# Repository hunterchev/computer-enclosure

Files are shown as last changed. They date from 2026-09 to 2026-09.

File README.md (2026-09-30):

# Small-computer display enclosure, v2

Redesign of the three files that came in (`reference/front.stl`, `back.stl`,
`foot.stl`). Same 108 x 94 mm footprint and the same 86 x 65 mm display window,
but the stand now plugs into the back plate, every fastener is a printed
thumbscrew that actually has threads to bite into, and the whole thing is one
parametric OpenSCAD file so it can be re-cut for the real board.

| file | print it? | what it is |
|---|---|---|
| `enclosure.scad` | – | the generator (needs the `BOSL2/` submodule) |
| `front.stl` | yes | bezel + walls + 4 threaded corner bosses, 108 x 94 x 38 |
| `back.stl` | yes | 6 mm back plate: standoffs, tray, vents, dovetail groove |
| `stand.stl` | yes | tilt stand (15 degree lean-back), prints on its side |
| `stand_upright.stl` | optional | same stand at 0 degrees (`tilt=0`), case stands straight up |
| `screws.stl` | yes | 5 thumbscrews: 4 x 18 mm (back plate), 1 x 24 mm (stand lock) |
| `fit_check.stl` | first | just the top 1 mm of the back plate with the standoffs. 15 min print to confirm the board sits where the model thinks it does |
| `renders/` | – | previews of everything |
| `reference/` | – | the original three STLs, untouched |

## Getting the files

BOSL2 is a git submodule pinned to the commit this was built with, so clone
with it:

    git clone --recurse-submodules https://github.com/hunterchev/computer-enclosure.git

If you already cloned without it: `git submodule update --init`. The STLs
are committed, so you only need BOSL2 to change the design and re-export.

## What was wrong with the original

- **The foot screwed to the wrong part.** Its four holes lined up with four
  4.4 mm holes in the *side wall* of the front shell, so the screws had to go
  in from inside the case, behind the computer. The foot's own holes were
  4 mm, 3 to 4 mm deep, and unthreaded: an M4 in that is a friction fit,
  not a fastening.
- **The corner screws were marginal.** 2.5 mm pilots in the shell posts with
  3.4 mm clearance holes in the plate is a correct M3 self-tap layout, but
  the posts were about 6 mm across in a 2.4 mm wall, so there was ~1.7 mm of
  plastic around each thread. Usable, not durable, and it needed bought M3s.
- **Nothing located the back plate** on the shell except those four screws.
- **No ventilation and no port openings** apart from one 10 x 4 mm notch in
  the bottom wall, which the foot then covered.
- The front's mystery: an 86 x 65 window and eight pegs on the back plate
  (posts at the tray edge with arms reaching inward, four of them carrying
  2.8 mm pins on a 25 x 55 mm pattern) around a 74.6 x 56.6 mm tray. The
  pegs, tray, and the small U-clip are reproduced at the original coordinates. None of this identifies a specific computer, and the
  PDF that came with the files was a FedEx label, not a datasheet.

## What changed

**Stand.** The back plate has a 14 mm dovetail groove down its lower half,
open at the bottom edge. The stand carries the matching tongue: lower the case
onto it and it seats on the stand's shelf, leaning back 15 degrees. It cannot
tip forward or back because the tongue is captive in the groove. A fifth
thumbscrew goes through the stand into a threaded boss on the inside of the
plate as a lock, 20 mm right of centre so it misses the groove and the clip;
the head sits in the open bay between the two gussets, so it is reachable
with the case assembled. Set `stand_lock = false` to drop it.

**Fasteners.** Printed thumbscrews: 7 mm major, 2.5 mm pitch, 45 degree
flanks (prints upright, no support), 12 mm knurled head with a coin slot. The
corner bosses are 12 mm round, fused into the wall corners, threaded 14 mm
deep, so each screw engages about 12 mm of thread. The female threads are cut
with 0.25 mm radial clearance (`thread_clear`); the mating was checked by
boolean intersection in the model. If your printer runs tight, raise it to
0.3. If you would rather use metal: `fastener = "m3"` switches the bosses to
2.5 mm pilots and the plate to 3.4 mm holes with a countersink.

**Fit.** The plate has a 1.5 mm lip that enters the shell (0.2 mm per side),
so it locates itself before the screws go in.

**Cooling.** Ten slits in the top wall and ten slots in the back plate under
the board. With the case leaning back, air enters the plate slots and leaves
through the top.

**Ports.** `cutouts` is a list of `[side, along, z, w, h]`; the default is
one 12 x 8 mm notch at the back edge of the right wall, next to the tray's cable gap.

## Fitting the real computer

The interior is what the original implied, not what any datasheet says.
Measure the board and change these in `enclosure.scad`:

| variable | default | measure |
|---|---|---|
| `standoffs` | the original 8 pegs | `[x, post_y, arm_end_y, pin]`: post at the tray edge, arm reaching inward, pin on the arm end. Pins on the right pair at (34.5, ±27.5) and (9.5, ±27.5), plain rests on the left |
| `mount_style` | `"pin"` | `"screw"` gives 2.2 mm holes for M2.5 self-tappers instead of pins |
| `standoff_h` | 12 | clearance needed under the board (tallest part on its underside + 1) |
| `tray` / `tray_on` | 74.6 x 56.6 x 6 | the rim under the board, cable gap on the right; turn off if nothing lives there |
| `edge_clip` | on | the small 12 mm U-clip by the bottom wall that the original had |
| `window` | 86 x 65 | visible area of the display, plus 0.5 mm each way |
| `cutouts` | one notch | one entry per port: which wall, where along it, how far from the bezel face |
| `depth` | 38 | bezel face to plate: display + board + standoffs + 6 mm plate must fit in `depth - bezel` |

Clear interior is 103.2 x 89.2 mm by 35 mm deep (bezel inner face to plate
inner face), minus the four 12 mm corner bosses. Print `fit_check.stl` first
and drop the board on it before printing `back.stl`.

## Printing

| part | orientation | notes |
|---|---|---|
| front | bezel face down | as exported. No supports; the window chamfer is on the bed side. 0.2 mm layers, 4 walls |
| back | outer face down | as exported. The groove's undercuts print as a widening void, no supports. 4 walls, 40 % infill |
| stand | on its side | as exported (a flat side face is on the bed). 30 % infill is plenty |
| screws | heads down | as exported. 0.16 mm layers if you have them, 100 % infill or 6 walls. PETG threads better than PLA |
| fit_check | as exported | anything |

Assembly: drop the board on the pins, put the plate on (lip locates it), four
screws from the back, finger-tight. Slide the case down onto the stand's tongue,
then the lock screw from behind, between the gussets.

## Regenerating

    openscad --backend=manifold -o front.stl  -D 'part="front"'  enclosure.scad
    openscad --backend=manifold -o back.stl   -D 'part="back"'   enclosure.scad
    openscad --backend=manifold -o stand.stl  -D 'part="stand"'  enclosure.scad
    openscad --backend=manifold -o screws.stl -D 'part="screws"' enclosure.scad

`part="assembly"` previews it standing on the stand. The `chk_*` parts are
interference checks and should each come out empty (OpenSCAD prints "Current
top level object is empty"); the screw checks use `chk_phase` because a screw
at the wrong rotation always looks like it collides with its nut.

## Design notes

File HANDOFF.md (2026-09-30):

# Handoff: small-computer display enclosure redesign

Written 2026-09-28 for whoever picks this up next (human or another chat).
Project folder: `~/3-D Print/computer enclosure/`. Everything below is true of
the files as they sit there now. The README.md in the same folder is the
user-facing print guide; this file is the engineering trail.

## 1. What the user asked for

Hunter (hunter.chevaillier@reardenresearch.com) dropped three STLs from
`~/Downloads` (`front.stl`, `back.stl`, `foot.stl`) plus a PDF, and asked:

1. redesign it so the stand "actually goes into the back plate",
2. redesign the whole thing to be better, because the screws looked wrong,
3. print some screws,
4. fit it to "this exact computer", model unknown.

Follow-ups in the same conversation:
- "make me one with a regular angle too" -> an upright (0 degree) stand was
  exported as `stand_upright.stl`, then the user said "actually dont". The
  file was left in place and marked optional. A reclined wedge variant was
  started and deliberately abandoned; nothing of it remains.
- "are all the pegs the same on the backplate" -> no, and the user then said
  "make them align like the back plate i gave you at the start". The pegs
  were rebuilt to the original's exact geometry (section 5).

The PDF was a FedEx shipping label with personal names and addresses on it,
not a datasheet. It contains nothing about the computer. Don't reproduce its
contents anywhere.

## 2. What the original files were (measured, not guessed)

Measured with trimesh cross-sections; originals are kept untouched in
`reference/`.

| part | size (mm) | what it is |
|---|---|---|
| front | 108 x 94 x 38 | open shell: 3 mm bezel with an 86 x 65 window, 2.4 mm walls, r=4 corners, four corner posts with 2.5 mm blind holes 8.3 deep at (±49, ±42), four 4.4 mm through-holes in the -Y wall at x=±30, z=10 and 28, one 10 x 4 notch in the -Y wall at the open edge |
| back | 108 x 94 x 3 | flat plate, 3.4 mm corner holes at (±49, ±42). On the inside: a 1.5 mm rim 77.6 x 59.6 outer, 6 tall, with a 12 mm gap on the +X side; eight 5 mm posts at y=±34.5 (x = 34.5, 9.5, -12.1, -33.9), 12 tall, each with a 3 mm arm reaching inward at the top; the four at x=34.5 and 9.5 carry 2.8 mm pins 2.1 tall at y=±27.5; the four at x=-12.1 and -33.9 are plain rests ending at y=±29.9; a 12 mm U-clip (two 1.5 mm fins, 5 deep, 9.5 tall) at x -6..9, y 38..43 |
| foot | 90 x 60 x 19 | wedge, 3 mm at one end to 19 mm at the other (14.9 degrees), four 4 mm blind holes 3 to 4 mm deep on the slope at x=±30 |

The foot's holes match the four holes in the front shell's -Y (bottom) wall.
So the case sat on the wedge by its bottom wall, screen leaning back 15
degrees, and the screws had to be driven from inside the case. The foot's
holes were unthreaded and too shallow to hold an M4. That is the "screws
don't work" complaint, and it is correct. The corner M3 self-tap layout was
sound but thin (about 1.7 mm of plastic around each thread).

Nothing in these files identifies the computer. The 25 x 55 pin pattern,
74.6 x 56.6 tray and 86 x 65 window don't match a Raspberry Pi, Jetson,
LattePanda, or anything else I could name. Earlier sessions on this machine
were searched (`~/LSRV Lab`, SLANT, Mac Studio) and none mention it.

## 3. What was built

One parametric OpenSCAD file, `enclosure.scad`, with BOSL2 as a git submodule in
`./BOSL2` (copied from the `low water pickup` project; version 2.0.751).
`part=` selects the output:

| part | file | print orientation as exported |
|---|---|---|
| front | `front.stl` | bezel face down |
| back | `back.stl` | outer face down (features up) |
| stand | `stand.stl` (tilt=15) and `stand_upright.stl` (tilt=0) | on its side, z 0..70 |
| screws | `screws.stl` | heads down; 4 x 18 mm shank + 1 x 24 mm |
| fit_check | `fit_check.stl` | top 1 mm of the plate plus everything on it, z from 0 |
| assembly | preview only | standing on the desk, tilted |
| chk_* | interference tests, should render empty | see section 6 |

Design decisions and why:

- **Envelope kept at 108 x 94.** The bezel window is still 86 x 65. Interior
  clear space is 103.2 x 89.2 by 35 deep, minus four 12 mm corner bosses.
- **Back plate is 6 mm thick** (was 3) so a 4 mm dovetail groove can be cut
  into its outer face with a 2 mm floor and the plate still prints flat,
  outer face down. A raised pad on the outside was tried first and rejected
  because it would have lifted the plate off the bed.
- **Stand attaches by dovetail.** Groove 14 mm wide at the face, 12 degree
  flanks, open at the plate's bottom edge, closed 4 mm above where the tongue
  ends. Tongue is on the stand, 42 mm long, with 0.15 mm per-side clearance
  (`dt_slop`). Case lowers onto the stand and sits on a shelf; the tongue
  stops it tipping either way. Dovetail profiles are hand-written polygons
  (`dovetail_profile`), not BOSL2's `dovetail()`, so the clearance math is
  explicit.
- **Stand shape** (side profile, world frame y=back, z=up): a block 10 mm
  behind the plate, 45 mm up it, a 30 mm shelf under the bottom wall, two
  8 mm gussets reaching 45 mm back with a 4 mm foot pad. The seat is made by
  subtracting the whole case envelope with 0.3 mm clearance, then the tongue
  is unioned on afterwards (it lives inside that envelope; the first attempt
  cut it off).
- **Printed thumbscrews.** 7 mm major, 2.5 mm pitch, 1.0 mm depth,
  90 degree thread angle (45 degree flanks, prints upright), 12 mm knurled
  head with a coin slot. `trapezoidal_threaded_rod` from BOSL2. Female
  threads use `internal=true` with `$slop = thread_clear/2` (BOSL2 adds
  `2*$slop` to the radius), so 0.25 mm radial clearance. Corner bosses are
  12 mm round fused into the wall corners, threaded 14 deep. `fastener="m3"`
  swaps in 2.5 mm pilots and 3.4 mm countersunk clearance holes.
- **Stand lock screw.** Fifth thumbscrew from behind the stand, through the
  block and the plate, into an 11 mm boss on the inside of the plate. It is
  at `lock_x=20, lock_y=-38` (20 mm right of centre, 9 mm above the bottom
  edge) so it misses the groove, the U-clip and the tray. The head sits in
  the open bay between the gussets. `stand_lock=false` removes all of it.
- **Registration lip** 1.5 mm on the plate, 0.2 mm per side clearance,
  notched with squares around the corner bosses (round notches missed the
  bosses' square corner fill and collided).
- **Vents**: ten 1.6 x 20 slits in the top wall, ten 1.6 x 40 slots in the
  plate under the board, skipping the groove region.
- **Cutouts** are a list `[side, along, z, w, h]`; default is one 12 x 8
  notch at the back edge of the right wall, beside the tray's cable gap.

## 4. Coordinate frames (the part most likely to bite)

Case frame: X width, Y height with bottom = -Y, Z depth with the bezel face
at z=0, shell open edge at z=38, plate inner face at z=38, plate outer face
at `Zb = 44`. Everything in the shell and plate is modelled here; standoffs
point toward -Z.

`part="back"` outputs `rotate([180,0,0]) translate([0,0,-Zb])`, i.e. a
rotation about X: x is preserved, y is flipped. So the printed plate seen
from the inside has the same x as the case frame. The original `back.stl`
is also "print frame, features up", and its x matches the case frame
directly. That is why the peg coordinates in `standoffs` are copied verbatim
from the original.

World frame (stand and assembly): X across (mirrored, `x_w = -x_c`, so the
viewer's right is +X when looking at the screen), Y backward, Z up, desk at
z=0. `place_case()` is `multmatrix([[-1,0,0],[0,s,c],[0,c,-s]])` plus a
translation that puts the case's bottom-back edge (0, -47, 44) at
`Q = (0, shelf_t)`. `c, s = cos, sin(tilt)`. Unit vectors in (y,z):
`nv=(c,-s)` back-normal of the plate, `pv=(s,c)` up the plate, `fv=(-c,s)`
forward along the bottom wall. The stand profile is built from Q with these.

`part="stand"` outputs `rotate([0,90,0]) translate([-stand_w/2,0,0])` so a
flat side face is on the bed and z runs 0..70.

## 5. Peg rebuild (last change made)

`standoffs` entries are `[x, post_y, arm_end_y, has_pin]`. Each makes: a
`post_d=5` cylinder at (x, post_y) from the plate to `standoff_h=12`; a 3 mm
thick stadium (hull of two 5 mm circles) from (x, post_y) to (x, arm_end_y)
at the top; if `has_pin`, a pin at (x, arm_end_y), `pin_d=2.8`, `pin_h=2.1`,
tapered from 2.3 at the tip. `mount_style="screw"` instead puts a 6 mm full
height post at the arm end with a 2.2 mm hole. The U-clip is at
`clip_pos=[1.5,-40.5]`, the tray gap on +X.

Verified against the original by slicing both meshes 1.5 mm below the pin
tops and 1.5 mm into the arms: all four pin centres and all eight arm
bounding boxes are identical to one decimal.

## 6. How things were verified

- Every STL: watertight, single body, z starts at 0, extents sane
  (trimesh). Front 63 cm3, back 59, stand 63, screws 4.6 total.
- Interference: `chk_stand_plate`, `chk_front_back`, `chk_screws_front`,
  `chk_screws_back`, `chk_screws_stand` are boolean intersections. Each
  must render empty ("Current top level object is empty") or with zero
  volume (coplanar-face slivers show up as zero-volume facets; that is
  fine). All passed for tilt=15 and, for the two stand checks, tilt=0.
- Screw-vs-nut checks need the screw rotated to its mating phase or they
  always show overlap. `chk_phase=90` mates the corner screws, `225` mates
  the lock screw. Established by sweeping 0..315 in 45 degree steps.
  Physically the screw just turns until it engages, so this is only a
  modelling artefact.
- Thread clearance was confirmed by measuring the internal cutter's radii
  (2.754 / 3.754) against the rod's (2.5 / 3.5).

## 7. Tooling notes

- OpenSCAD 2026.09.12 at `/opt/homebrew/bin/openscad`. Always use
  `--backend=manifold`; threads render in seconds instead of minutes.
- System Python has no trimesh and pip is PEP-668 locked. A venv with
  `trimesh manifold3d shapely numpy` was made in the session scratchpad
  (gone now). Recreate: `python3.12 -m venv venv && venv/bin/pip install
  trimesh manifold3d shapely numpy`.
- The user's shell is zsh. `$VAR` does not word-split, so putting several
  `-D` flags in one variable passes them as a single argument and OpenSCAD
  reports a bogus "syntax error" on a line past the end of the file. Pass
  flags literally or use `${=VAR}`.
- Don't name a scratch script `inspect.py`; it shadows the stdlib and
  breaks numpy import.
- Renders: `openscad -o x.png -D 'part="..."' --camera=... --colorscheme=
  Tomorrow enclosure.scad`. Ortho top views come out looking at the wrong
  face; not worth fighting.

## 8. Status

Done and verified: all five printable STLs, README, renders, interference
checks. Nothing has been printed yet as far as I know.

Not done, because it can't be without the user:
- **Identify or measure the computer.** Until then the interior is a faithful
  copy of the original's assumptions, which may or may not fit. The user
  should print `fit_check.stl` first (about 15 minutes) and drop the board
  on it.
- Once the board is known, edit `standoffs`, `cutouts`, `window`,
  `standoff_h`, possibly `tray`/`edge_clip`, and regenerate `back.stl`,
  `front.stl`, `fit_check.stl`.
- Thread fit on the user's printer is unproven. If the printed screws are
  tight, raise `thread_clear` to 0.3 and re-export `front.stl`, `back.stl`,
  `screws.stl` (only the female side changes, but export all three to be
  safe).

Open judgement calls the next person may want to revisit:
- Whether the U-clip and tray should stay. They are there only because the
  original had them; if the real board doesn't use them, `edge_clip=false`
  and `tray_on=false` free up the floor.
- `stand_upright.stl` was asked for and then retracted in the same breath.
  It costs nothing to keep.
- The reclined "wedge under the back plate" idea (tilt near 75, no gussets,
  no lock screw) is achievable with the existing parameters if the user
  ever wants the original foot's posture back, but the stand profile was
  not tuned for it.

## 9. Regenerate everything

    cd "~/3-D Print/computer enclosure"
    for p in front back stand screws fit_check; do
      openscad --backend=manifold -o $p.stl -D "part=\"$p\"" enclosure.scad
    done
    openscad --backend=manifold -o stand_upright.stl -D 'part="stand"' -D tilt=0 enclosure.scad

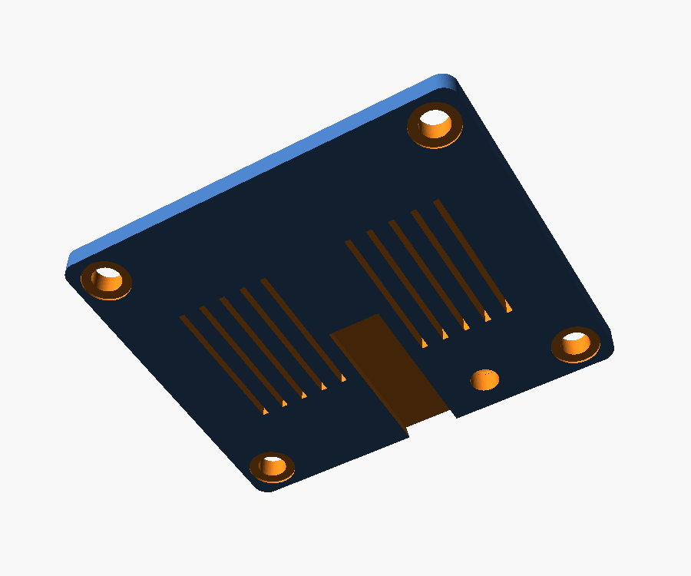
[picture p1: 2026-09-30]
renders/back_outside.png

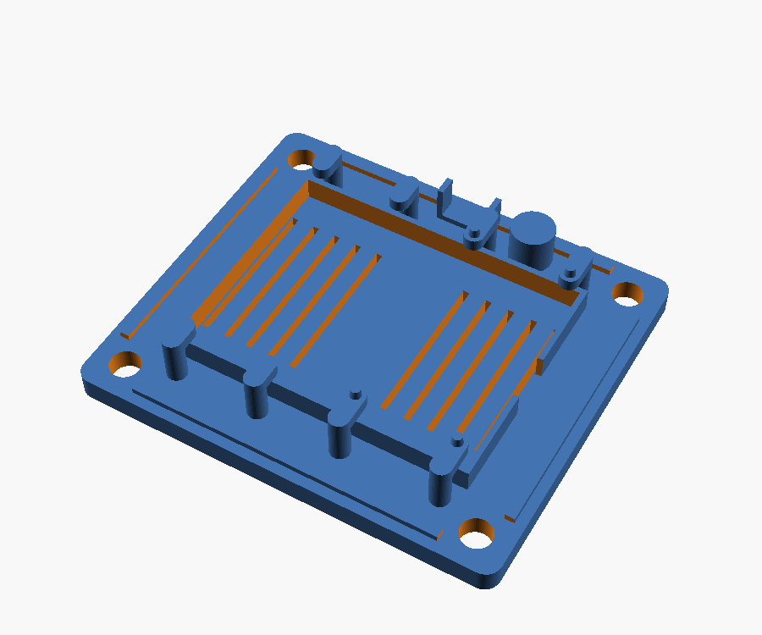
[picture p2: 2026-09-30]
renders/back_inside.png

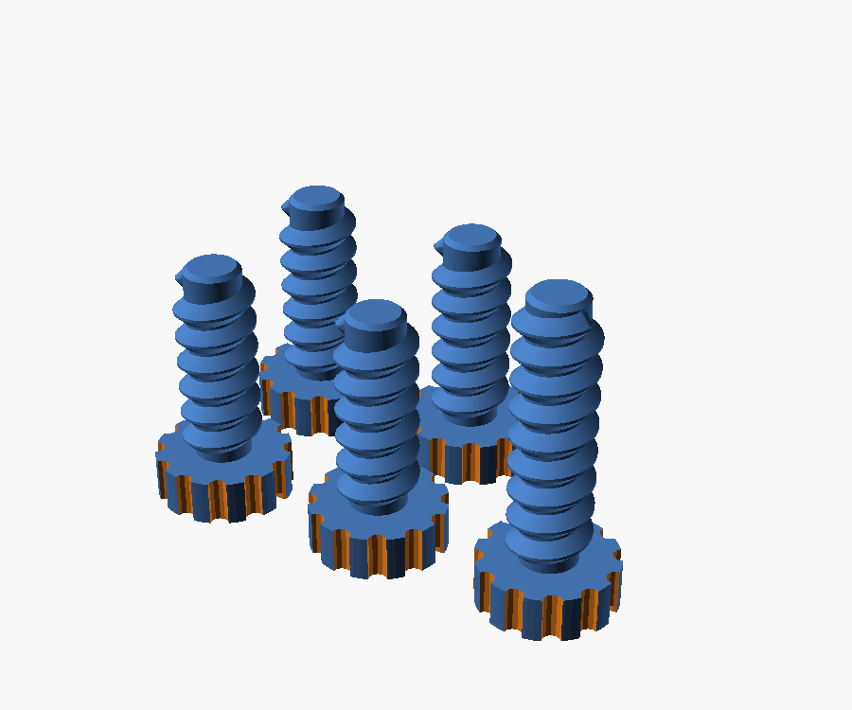
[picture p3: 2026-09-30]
renders/screws.png

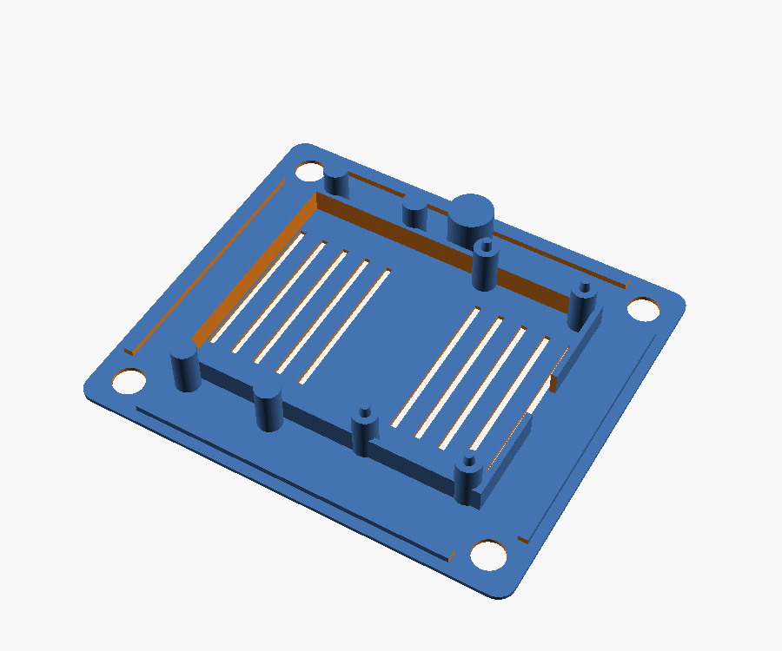
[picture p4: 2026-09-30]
renders/fit_check.png

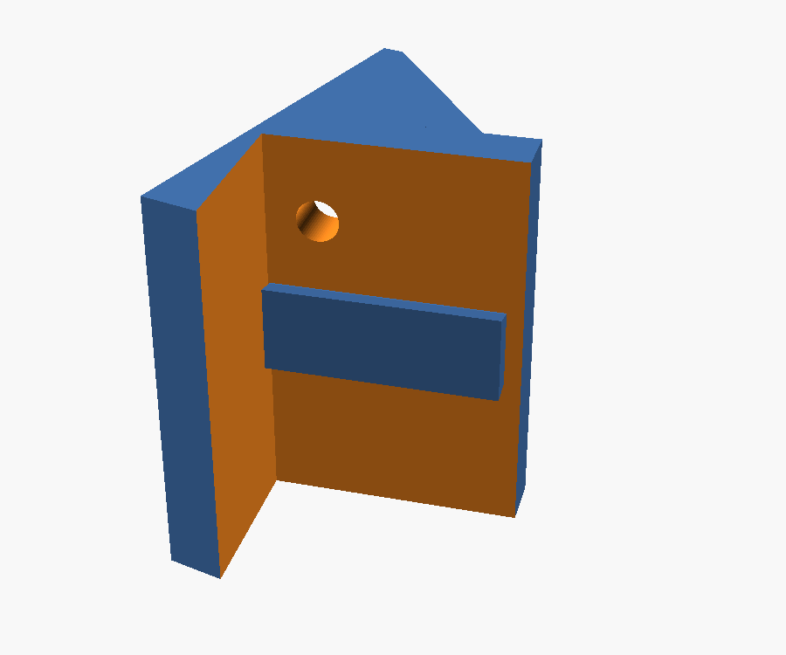
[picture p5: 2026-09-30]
renders/stand_seat.png

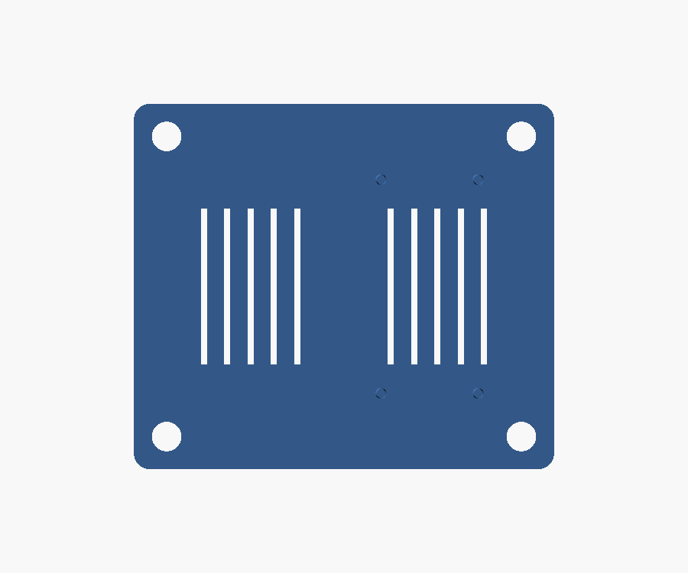
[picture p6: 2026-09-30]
renders/back_inside_top.png

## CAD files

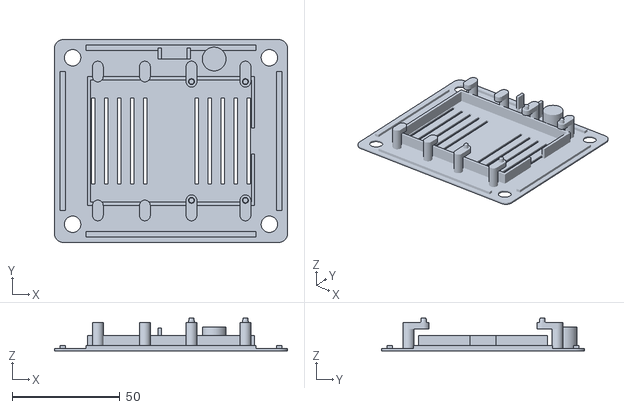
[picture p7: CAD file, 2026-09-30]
fit_check.stl
108.0 x 94.0 x 15.1

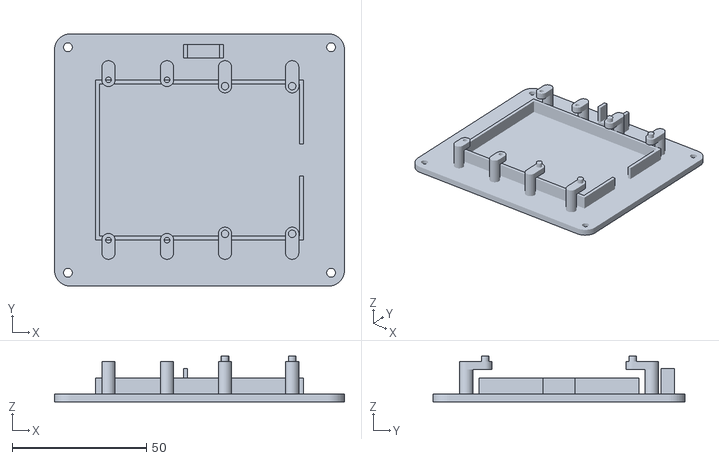
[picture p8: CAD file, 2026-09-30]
reference/back.stl
108.0 x 94.0 x 17.1

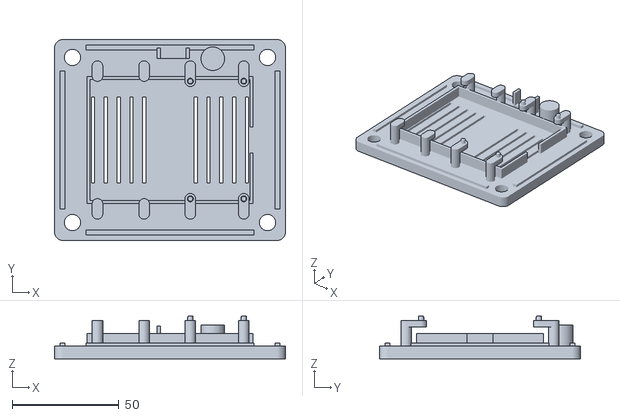
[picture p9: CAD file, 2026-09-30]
back.stl
108.0 x 94.0 x 20.1

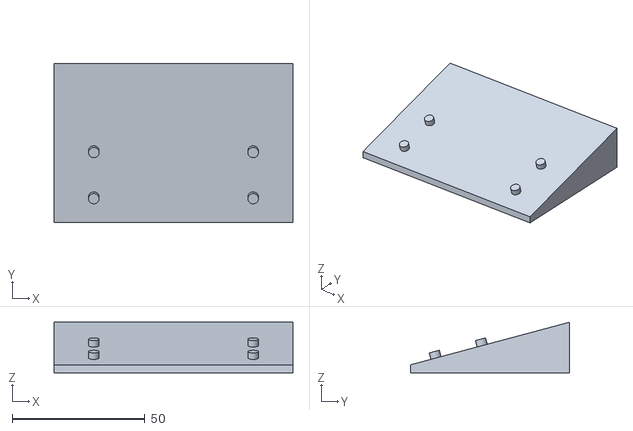
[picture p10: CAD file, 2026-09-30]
reference/foot.stl
90.0 x 60.0 x 19.1

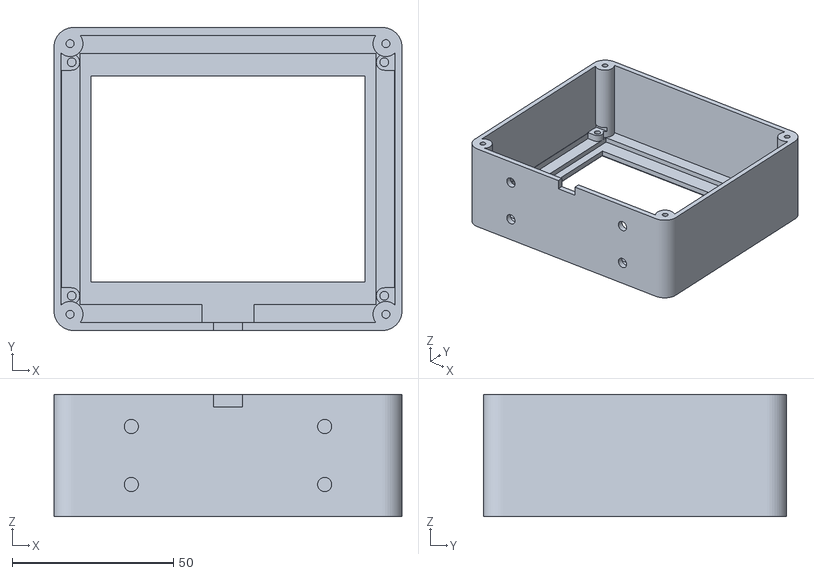
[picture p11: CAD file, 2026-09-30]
reference/front.stl
108.0 x 94.0 x 38.0

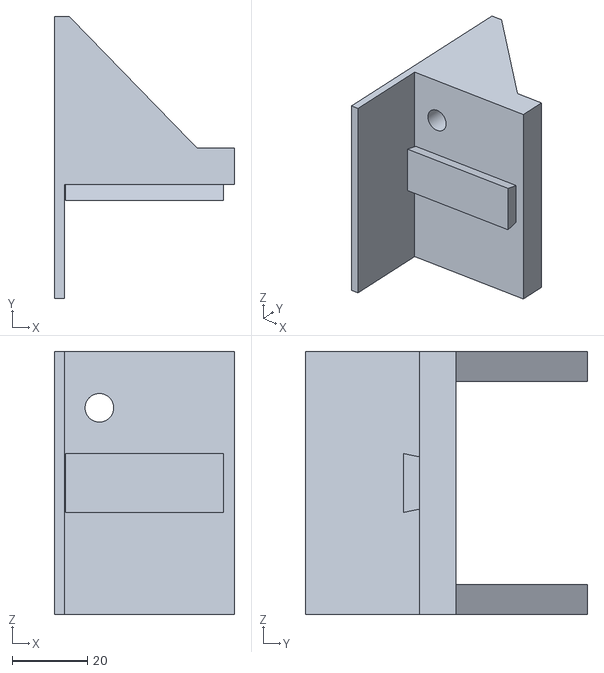
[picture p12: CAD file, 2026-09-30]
stand_upright.stl
48.0 x 75.0 x 70.0

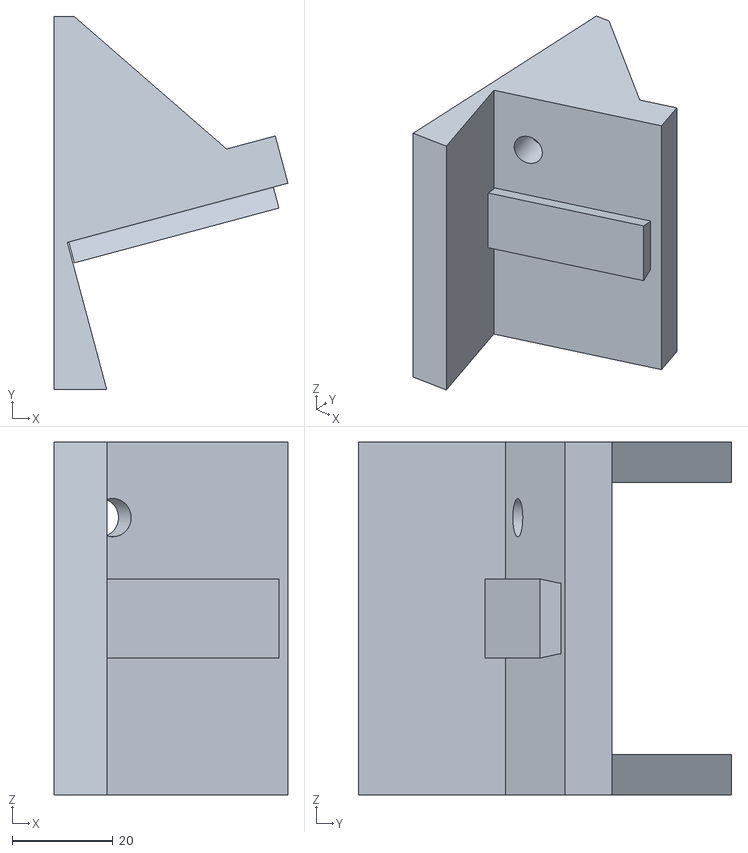
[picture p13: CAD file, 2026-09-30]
stand.stl
46.4 x 74.0 x 70.0

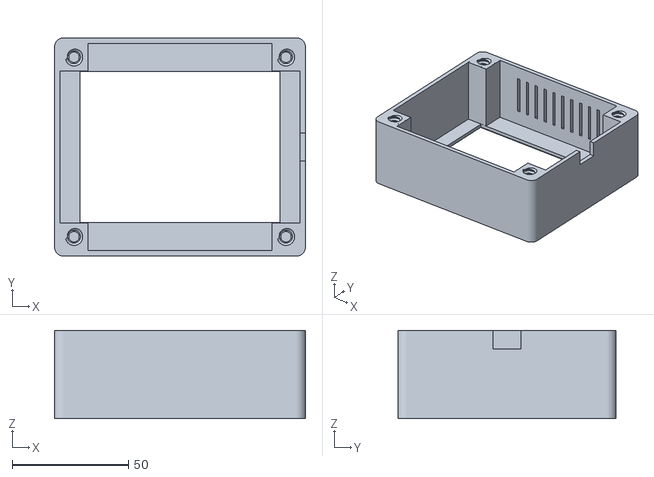
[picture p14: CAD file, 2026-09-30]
front.stl
108.0 x 94.0 x 38.0

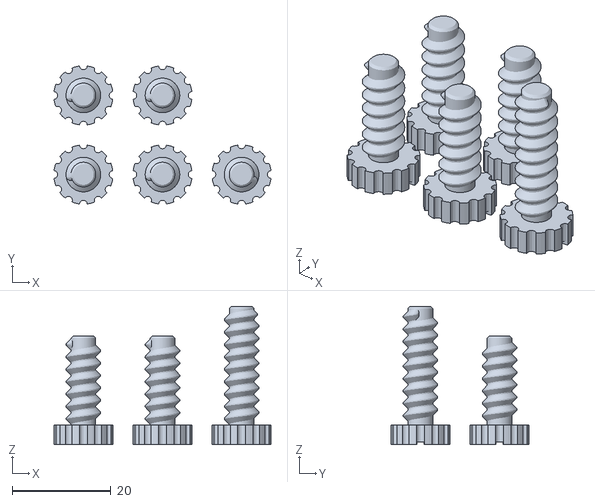
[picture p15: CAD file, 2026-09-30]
screws.stl
43.9 x 27.9 x 28.0

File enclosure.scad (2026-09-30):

// =====================================================================
// SMALL-COMPUTER DISPLAY ENCLOSURE  --  v2 redesign
//
//   part="front"     front shell: bezel with window, walls, 4 corner bosses
//   part="back"      back plate: board standoffs, tray, vents, dovetail groove
//   part="stand"     stand: slides into the back plate's dovetail, 15 deg tilt
//   part="screws"    printed thumbscrews: 4 for the back plate + 1 stand lock
//   part="assembly"  everything standing on the stand (preview only)
//   part="fit_check" 3 mm slice of the back plate: quick print to check the
//                    board sits on the standoffs before printing everything
//
// All dimensions mm.  The case frame: X = width, Y = height (bottom = -Y),
// Z = depth with the bezel face at z=0 and the back plate outer face at
// z = depth + plate_t.  Same envelope (108 x 94) as the original files.
//
// THE COMPUTER IS NOT IDENTIFIED.  Everything under "BOARD" below is what the
// original back plate implied.  Measure the real board and edit:
//   standoffs  -> where its mounting holes / support points are
//   cutouts    -> where its ports come out
//   window     -> the visible area of its display
// Requires BOSL2 (vendored in ./BOSL2).
// =====================================================================

include <BOSL2/std.scad>
include <BOSL2/threading.scad>

part = "assembly";   // front | back | stand | screws | assembly | fit_check

$fn = 64;

// ---- envelope --------------------------------------------------------
OW        = 108;    // outer width  (X)
OH        = 94;     // outer height (Y)
depth     = 38;     // front shell, bezel face to open edge
wall      = 2.4;    // side walls (6 x 0.4 mm perimeters)
bezel     = 3;      // front plate thickness
corner_r  = 4;      // outer vertical corner radius
window    = [86, 65];   // opening in the bezel (display visible area)
window_chamfer = 1.2;   // 45 deg chamfer on the outside of the window edge

// ---- back plate ------------------------------------------------------
plate_t   = 6;      // thick enough to hold the dovetail groove (4) + 2 floor
lip_h     = 1.5;    // registration lip that enters the shell
lip_clear = 0.2;    // per side, lip to shell wall

// ---- fasteners (back plate to shell) ----------------------------------
fastener  = "printed";  // "printed" thumbscrews (below) or "m3" self-tapping
boss_d    = 12;         // corner boss diameter
// printed screw: coarse 45 deg-flank thread that prints upright without support
scr_d        = 7;       // thread major diameter
scr_pitch    = 2.5;
scr_depth    = 1.0;     // radial thread depth  (minor = 5.0)
scr_len      = 18;      // threaded shank length, back plate screws
lock_len     = 24;      // threaded shank length, stand lock screw
head_d       = 12;
head_h       = 4;
thread_clear = 0.25;    // radial clearance printed into the female threads
boss_thread  = 14;      // threaded depth in each corner boss
// M3 option
m3_pilot     = 2.5;     // self-tapping pilot in the bosses
m3_clear     = 3.4;

// ---- BOARD (edit for the real computer) ------------------------------
// Board supports, copied from the original back plate: a 5 mm post standing
// at the tray's edge, a 3 mm thick arm reaching inward at the top, and on
// four of them a 2.8 mm locating pin at the arm's end (pins 25 x 55 apart).
// Each entry: [x, post_y, arm_end_y, has_pin], same coordinates as the
// original file (printed plate seen from the inside, pins on the right).
standoffs = [
    [ 34.5,  34.5,  27.5, true ], [ 34.5, -34.5, -27.5, true ],
    [  9.5,  34.5,  27.5, true ], [  9.5, -34.5, -27.5, true ],
    [-12.1,  34.5,  29.9, false], [-12.1, -34.5, -29.9, false],
    [-33.9,  34.5,  29.9, false], [-33.9, -34.5, -29.9, false],
];
standoff_h   = 12;      // inner face of the plate to the underside of the board
post_d       = 5;
arm_t        = 3;
mount_style  = "pin";   // "pin" (drop-on pins), "screw" (M2.5 holes), "none"
pin_d        = 2.8;
pin_h        = 2.1;
mount_hole_d = 2.2;     // M2.5 self-tapping
// small U-clip near the bottom wall, as in the original (12 mm slot, 5 deep, 9.5 tall)
edge_clip    = true;
clip_pos     = [1.5, -40.5];   // centre
// tray: a 6 mm rim on the plate under the board, as in the original
tray_on      = true;
tray         = [74.6, 56.6, 6];   // inner length, inner width, rim height
tray_wall    = 1.5;
tray_gap     = 12;      // cable gap in the rim
tray_gap_side = 1;      // +1 = right (+X) wall side as in the original, -1 = left

// ---- port cutouts in the shell walls ---------------------------------
// [side, along, z_centre, width, height]
//   side  : "left" (-X), "right" (+X), "top" (+Y), "bottom" (-Y)
//   along : position along that wall (x for top/bottom, y for left/right)
//   z     : centre measured from the bezel face; > depth-h/2 makes a notch
cutouts = [
    ["right", 0, 34, 12, 8],   // cable notch at the back edge of the right wall, by the tray gap
];

// ---- ventilation ------------------------------------------------------
vents_top   = true;   // slits in the top wall
vents_back  = true;   // slots in the back plate under the board
vent_w      = 1.6;

// ---- stand ------------------------------------------------------------
// tilt=15 -> stand.stl (leaning back), tilt=0 -> stand_upright.stl. The back
// plate is the same for any angle.
tilt        = 15;     // lean-back angle
stand_w     = 70;     // width across
shelf_len   = 30;     // shelf under the bottom wall
stand_back  = 45;     // how far the feet reach behind the back plate
block_t     = 10;     // stand material behind the back plate
block_h     = 45;     // contact height up the back plate
gussets     = true;   // two side gussets reaching back to stand_back (off for a flat wedge)
gusset_t    = 8;      // the two side gussets
gusset_h    = 35;
dt_w        = 14;     // dovetail width at the plate face
dt_h        = 4;      // dovetail depth into the plate
dt_ang      = 12;     // dovetail flank angle
dt_len      = 42;     // tongue length up the plate (ends inside the block)
dt_slop     = 0.15;   // per-side clearance in the groove
stand_lock  = true;   // lock thumbscrew through the stand into the plate
lock_up     = 9;      // lock screw height above the bottom edge
lock_x      = 20;     // lock screw offset to the right, clear of the clip and the groove
lock_boss_d = 11;
shelf_t     = 3;      // stand material under the case's lowest edge

// ---- derived ----------------------------------------------------------
Zb   = depth + plate_t;            // back plate outer face
bx   = OW/2 - wall - boss_d/2;     // corner boss centres
by   = OH/2 - wall - boss_d/2;
boss_xy = [[bx,by],[-bx,by],[bx,-by],[-bx,-by]];
lock_y  = -OH/2 + lock_up;
dt_wt   = dt_w + 2*dt_h*tan(dt_ang);   // dovetail width at the bottom of the groove
eps = 0.01;

// ---- 2D helpers ------------------------------------------------------
module rrect(w, h, r) offset(r=r) square([w-2*r, h-2*r], center=true);

// =====================================================================
// PRINTED SCREW
// =====================================================================
module screw_thread(len, internal=false) {
    trapezoidal_threaded_rod(d=scr_d, l=len, pitch=scr_pitch,
        thread_angle=90, thread_depth=scr_depth,
        internal=internal, bevel2=internal?false:true,
        anchor=BOTTOM, $slop = internal ? thread_clear/2 : 0);
}
// modelled head-down, ready to print
module printed_screw(len) {
    difference() {
        union() {
            // knurled head
            difference() {
                cylinder(d=head_d, h=head_h);
                for (a=[0:30:359]) rotate(a) translate([head_d/2, 0, -1])
                    cylinder(d=1.6, h=head_h+2, $fn=12);
            }
            translate([0,0,head_h-eps]) screw_thread(len+eps);
        }
        // coin / flat-blade slot in the exposed face
        translate([0,0,-1]) cube([head_d+2, 1.4, 2*1.6], center=true);
    }
}
// female thread cutter, anchored at the mouth (z=0), going down -Z
module screw_hole(depth_mm) {
    if (fastener == "printed")
        translate([0,0,-depth_mm]) screw_thread(depth_mm + 1, internal=true);
    else
        translate([0,0,-depth_mm]) cylinder(d=m3_pilot, h=depth_mm+1);
}

// =====================================================================
// FRONT SHELL
// =====================================================================
module wall_cut(c) {
    side=c[0]; along=c[1]; zc=c[2]; w=c[3]; h=c[4];
    if (side=="left")   translate([-OW/2, along, zc]) cube([3*wall, w, h], center=true);
    if (side=="right")  translate([ OW/2, along, zc]) cube([3*wall, w, h], center=true);
    if (side=="top")    translate([along,  OH/2, zc]) cube([w, 3*wall, h], center=true);
    if (side=="bottom") translate([along, -OH/2, zc]) cube([w, 3*wall, h], center=true);
}
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
